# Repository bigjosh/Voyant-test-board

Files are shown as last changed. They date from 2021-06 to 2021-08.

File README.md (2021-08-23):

# Voyant Test Board

## Overview 

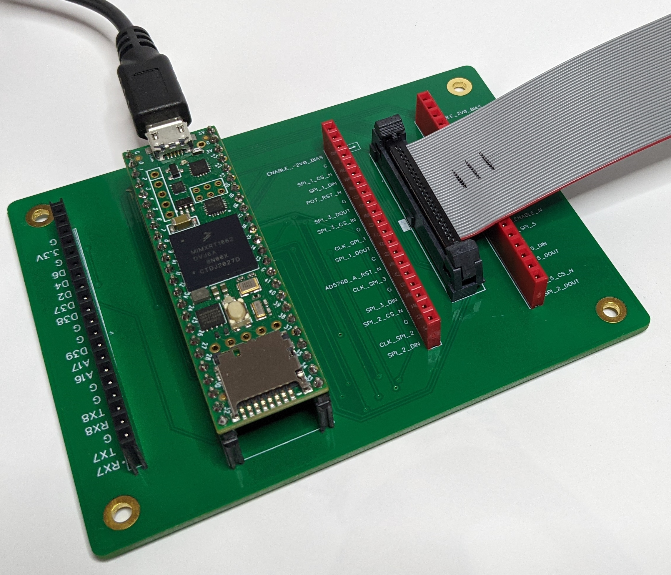
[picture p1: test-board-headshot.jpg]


A thin board+firmware that provides...

1. a text-based USB host serial command interface
2. an M50 connector with SPI and digital IO targets on the midboard via the M50 connector
2. a pass-thru serial port labeled "TEC_UART" via the M50 connector
3. an auxiliary header with additional pins available for digital IO, SPI, analog IO, and serial. 

Not that all pins from the M50 connector are also directly available via break-out headers for debugging. 

## Usage

### M50 labels

Note that all of the labels on the M50 pins are from the other side's point of view. For example, `TEC_RX` is going out of the test board into the `TEC`, and `TEC_TX` is going out of the `TEC`. `SPI_1_DIN` is going out of the test-board and into the `DIN` pin of the AD7490 on the mid-board  and `SPI_5_DOUT` goes out of the `SDO` (Slave Data Out) pin of the AD5142 and into the `MISO` (Master In, Slave Out) of the test-board.   

### Serial ports

When you connect the test board to a host computer via USB, you should see two virtual serial ports appear. One of these is the `command` and one is the `TEC_UART`, which is a pass-thru port. 

The command port is usually the first one, but not always. The most reliable way to tell is to load the Arduino IDE and 
look under "Tools->Port" and the command port will show up labeled as `Teensy`. The other new port will be the `TEC_UART` pass-thru.

#### `TEC_UART` pass-thru serial port

This is a direct pass-thru from the virtual USB port on the host to the `TEC_UART` RX and TX pins on the M50 connector. The baud rate on the serial port on the connector will track whatever the baud rate host serial port was set to when last connected to.

Note that the parity and bits are always N,8,1 but this can be changed in the firmware if needed.

#### Additional pass-thru serial ports

You can add additional serial pass-thru ports to the `uart_bridges` array in the firmware. You will likely want to connect them to either `Serial7` or `Serial8`, which are both available on the aux connector. 

To enable the corresponding USB virtual serial port, change the `USB Type` in `Tools->Board` in the Arduino IDE to `Tripple Serial` before downloading the new code. 

#### `command` serial port   

This serial connection accepts commands from the host according to the [API below](#api). These commands can send and receive data on the SPI ports, set the state of digital IO lines on the connector, and add delays.

Note that this virtual port will always run at USB maximum speed regardless of what baud rate it is set to on the host. That rate could be as high as 480Mbs, limited mostly by the host's USB bandwidth.

### SPI targets

There are a total of 6 SPI targets and each has an identifying one character tag name that is used to address the target in the API. Each SPI target has 4 associated pins: MISO, MOSI, CLK, and CS. The test-board is always the master and MISO is the only pin on each SPI port that is an input to the test-board. Any optional RESET pins are controlled using the [digital IO set command](#Digital-IO-Set-Request) below.   

Again, remember that the labels on the M50 connector are from the mid-board's point of view! A `DOUT` label on the test board means that pin is an output from the mid-board and an input to the test-board!

SPI targets `1`-`5` are labeled on the M50 connector. 

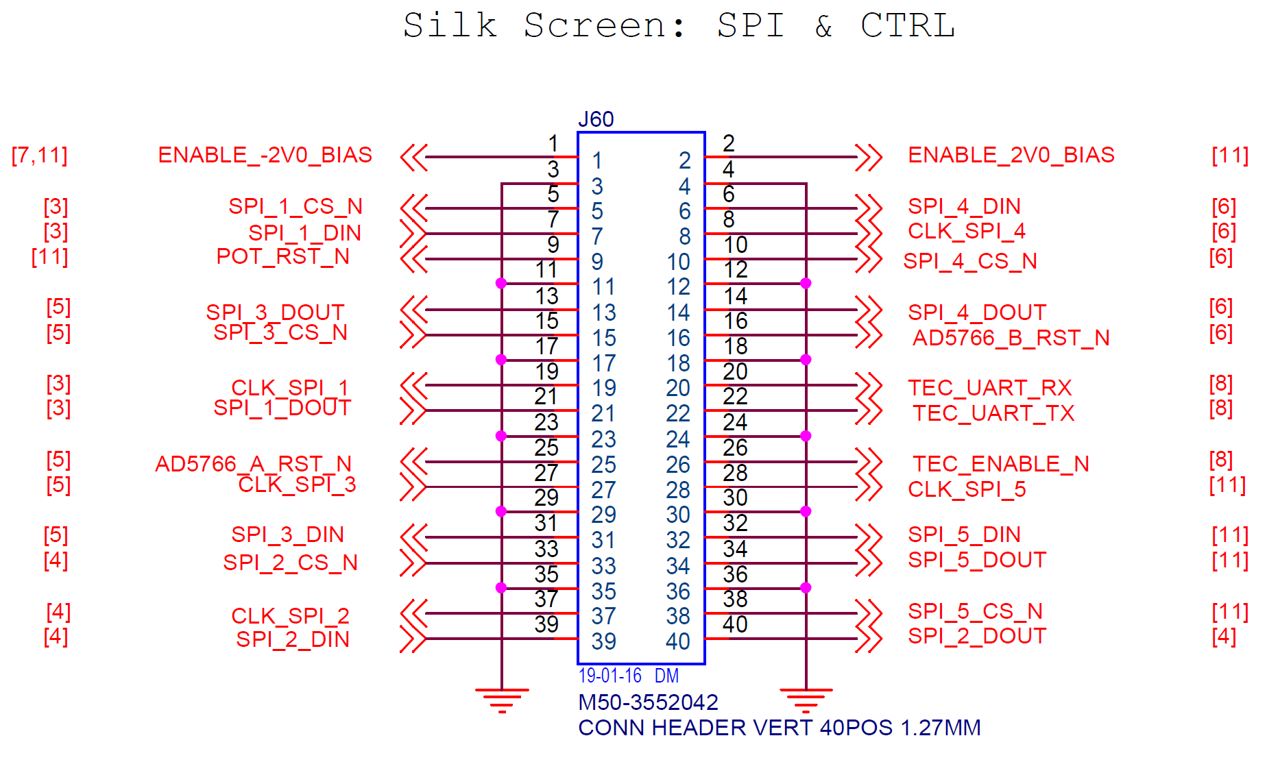
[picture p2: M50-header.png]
  

SPI target `A` is on the aux header with these pins (`MISO` is the only pin input to the test-board)...

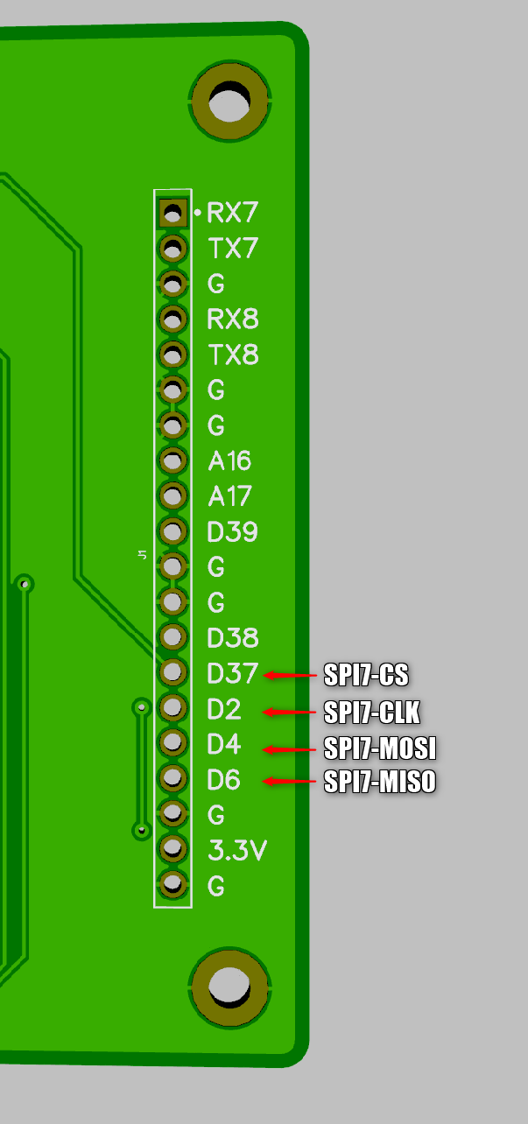
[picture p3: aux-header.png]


Note that currently all SPI ports run at 1MHz to reduce the chances of signal quality problems, but this can be increased on any or all ports with changes to the firmware. 

### Digital out targets

These are general purpose digital pins that can output either 0 volts or 3.3 volts. They are each capable of sinking or sourcing up to 10mA. Digital outputs are all initialized to `0` on power up. 

They are listed in the [IO target tags table](#IO-target-tags) and are controlled using the [digital IO set command](#Digital-IO-Set-Request) below. 

## API

The API is a set of ASCII text commands and responses that are sent over the command serial port. Each command and response is a line of ASCII text. Requests can be terminated with any combination of carriage returns and/or line feeds. Responses are always terminated with a carriage return character (ASCII 13, or '\r') and a newline character (ASCII 10, or '\n').

Every command sent to the test board generates a single response back to the host. All commands are currently synchronous so the responses will always be sent in the same order as the their requests.   

The maximum line length in either direction is currently 255 bytes.

### Cheat Sheet

If necessary, download the firmware to the board per these [instructions](#Development-environment).

Connect to first USB serial port that shows up on your host. All requests and responses are single line of ASCII text.

`T1771FF5600` where "T"=Transfer rerquest, "1"= the tag for SPI1 target, sends the three bytes 77h, 1fh, f5h. Returns with...

`S567483` where "S"=Transfer response and 56h, 74h, and 83h are the bytes read from the SPI. 

`;This is a comment becuase it starts with semicolon. Send or ignore me.` 

`IN1` where "I" = Set digital IO pin request, "N"= the tag for `ENABLE_-2V0_BIAS` pin, "1" = Set pin HIGH. Returns with...

`H` where "H" = Set completed.  

`D1000` where "D" = Delay command and "1000" = 1000 milliseconds. Returns (after the delay) with...

`C` where "C" = Delay completed. 

Getting back an `E` indicates an error. A comment that tells you why.

All commands are synchronous (for now).

All SPI and digital IO signals are 3.3 volts.

All SPIs run at 1Mhz (for now). 

### Target Tags

These 1 char tags are sent with each SPI and IO command to specify which target. The actual tag char is arbitrary, but I tried to pick ones that make sense and are easy to remember.    

#### SPI target tags

```
  // Taken directly from schamtics. The numbers here refer to the pin numbers on the Teensy. 
  // The tags are taken from the SPI labels on the M50 connector diagram except for `A` which is on the AUX header.
  
  // spi_target( uint8_t mosi, uint8_t miso, uint8_t clk , uint8_t cs , uint32_t bps ) 
  
  {'1', Spi_target( 33 , 32 , 31 , 30 , SPI_BPS ) }, 
  {'2', Spi_target( 22 , 21 , 20 , 19 , SPI_BPS ) }, 
  {'3', Spi_target( 26 , 12 , 13 ,  0 , SPI_BPS ) }, 
  {'4', Spi_target( 11 , 12 , 13 , 10 , SPI_BPS ) }, 
  {'5', Spi_target( 17 , 16 , 15 , 14 , SPI_BPS ) }, 
  
  {'A', Spi_target(  4 ,  6 ,  2 , 37 , SPI_BPS ) },        // On the aux header on the right side of the PCB
```

#### IO target tags

```
  // key in the map is the `target` char that the API uses to specify which IO target. 
  // The tags are arbitrary (but meant to hopefully be mnemonic)   
  // The pin refers to the Teensy pin number. 
  // io_target( uint8_t pin ) 

  // The comment is the label on the pin on the M50 connector
  
  {'N', Io_target( 24 ) },    // ENABLE_-2V0_BIAS
  {'P', Io_target( 25 ) },    // ENABLE_2V0_BIAS
  
  {'3', Io_target(  3 ) },    // AD5766_A_RST_N (SPI3)
  {'4', Io_target(  9 ) },    // AD5766_B_RST_N (SPI4)
  {'5', Io_target( 18 ) },    // POT_RST_N      (SPI5)

  {'T', Io_target(  5 ) },    // TEC_ENABLE_N   (TEC_UART)

  // The comment is the label on the Aux header  

  {'9', Io_target( 39 ) },    // D39
  {'8', Io_target( 38 ) },    // D38
```

### Protocol

#### Omnibus Error Response

The error response is sent in response to any invalid or malformed line. 

If `DEBUG` is `#defined` as `1`, then each error response will be preceded by a comment with text describing the error condition.

All errors should be considered exceptions and indicate either a logic problem or a config mismatch. 

##### Format 

| Content | Bytes | Desc |
| - | - | - |
| `E` | 1 | Specifies Error Response |

##### Example
```
;Invlaid hex digit in SPI transfer
E
```

#### SPI Transfer Request

Sends a series of bytes to an SPI target and simultaneously reads the same number of bytes from that target.

##### Request Format:

| Content | Bytes | Desc |
| - | - | - |
| `T` | 1 | Specifies transfer request |
| tag | 1 | Specifies SPI target port. From [SPI target tags list](#SPI-target-tags) above. |  
| data | 2,4,6,... | Variable length of bytes to send, each as a two digit ASCII hex number |

##### Example
```
TA0C0A0F0E90
```

Sends the bytes 0x0c, 0x0a, 0x0f, 0x0e , 0x90 to SPI port target `A` (which is on the AUX header).   

##### Transfer Response

| Content | Bytes | Desc |
| - | - | - |
| `S` | 1 | Specifies transfer success response |  
| data | 2,4,6,... | Variable length of bytes received, each as a two digit ASCII hex number. |

The number of bytes received will always be equal to the number sent in the corresponding transfer request command. 

For now, all SPI transfers are synchronous so the response will immediately follow the request.  

#### Digital IO Set Request

Sets the output voltage on one of the IO pins. 

##### Request Format:

| Content | Bytes | Desc |
| - | - | - |
| `I` | 1 | Specifies IO Set command |
| tag | 1 | Specifies target IO port. From [IO target tags list](#IO-target-tags) above. |  
| `0` or `1`  | 1 |  `0`= sets pin to 0 volts, `1`=sets pin to 3.3 volts.  |

##### IO Response

| Content | Bytes | Desc |
| - | - | - |
| `H` | 1 | Specifies IO set success response |  

#### Delay Request

Adds a delay while processing requests. 

##### Request Format:

| Content | Bytes | Desc |
| - | - | - |
| `D` | 1 | Specifies IO Set command |
| millis | variable | Specifies number of milliseconds to pause. |  

Note that millis will overflow if number specified in command is larger than 32 bits. 

## Development environment

To edit the firmware, you need to follow these steps to install the development environment...
 
``` 
 1. Install Arduino IDE https://www.arduino.cc/en/software
 2. Install Teensiduino from https://www.pjrc.com/teensy/td_download.html 
 3. Set the following in the Arduino Tools menu...
 
    Board     = Teensy->Teensyduino->Teensy 4.1
    USB Type  = Dual Serial
    CPU Speed = 600Mhz (default)
    Port      = (find the Teensy 4.1 board on this list)
 ```

Then open the `firmware.ino` file in the `software` section of this repo using the Arduino IDE, make any desired changes, and then click on the right-pointing arrow in the upper left corner of the IDE window. This will upload the new code to the Teensy board and run it. 

### Examples

Copy and paste these into a `putty` window connected to the command port. 

#### SPI1 (AD7490)

```
;First send two transactions with DIN high to reset all the state bits
T1FFFF
T1FFFF
;Read a sample from address 0 ( 0b10aa aa11 0101 with aaaa=0000. Note the trailing 0 is ignored, just there to clock out final 4 bits )
; Send twice for this demo since the response for a command is clocked out on the NEXT request
T18350
T18350
; The above command should generate a response `S10xxx` where `0` is the address we requested above and xxx is the reading
;Read a sample from address 1 ( 0b10aa aa11 0101 with aaaa=0001. Note the trailing 0 is ignored, just there to clock out final 4 bits )
; Send twice for this demo since the response for a command is clocked out on the NEXT request
T18750
T18750
; The above command should generate a response `S11xxx` where `1` is the address we requested above and xxx is the reading
;Read a sample from address 15 ( 0b10aa aa11 0101 with aaaa=1111. Note the trailing 0 is ignored, just there to clock out final 4 bits )
; Send twice for this demo since the response for a command is clocked out on the NEXT request
T1BF50
T1BF50
;The above command should generate a response `S1fxxx` where `1` is the address we requested above and xxx is the reading
; With an AREF of 2.5V and an AA battery attached to input #15, I get a response of  Sf42a 
```

#### SPI2 (AD7124)

```
;Reset command
T2FFFFFFFFFFFFFFFF
;Read command (high bits 0b01xxxxxx) on `CHANNEL_0` register ((0x09 or 0bxx001001). Trailing `0000` clocks out the result.   
T2490000
;The above command should generate a response `S008001` where `00` is always the first byte on this chip,
; and the `8001` is the reset value of the register.   
```

#### SPI3 & SPI4 (AD5766)

Note these commands address `AD5766-A` on SPI3, but will work on `AD5766-B` on SPI4 if you change all the targets to `4`.

```
;~Reset=LOW (resets chip)
I30
; T10=100ns, so 1ms more than enough
D1
;~Reset=HIGH
I31
; "Minimum time between a reset and the subsequent successful write is typically 25 ns."
D1
; "Always issue a software reset before writing to the span register."
; Full Software reset = 0b0111 0000 0001 0010 0011 0100
T3701234
; "outputs are clamped to ground...until a valid write sequence is made to the span register"
; Set span Full Scale , -10V to 10V = 0b0100 0000 0000 0000 0001 0110
T3400017
;Trigger scope
D1
; Make an interesting ramp on OUT0....
; Write 16 bit value to to DAC register 0 = 0010 0000 vvvv vvvv vvvv vvvv
T3201111
D1
T3202222
D2
T3203333
D3
T3205555
D5
;Half way
T3208000
D5
T320AAAA
D9
T320FFFF
D14
;Bring it back home
T3200000
;Go check your osciliscope

```

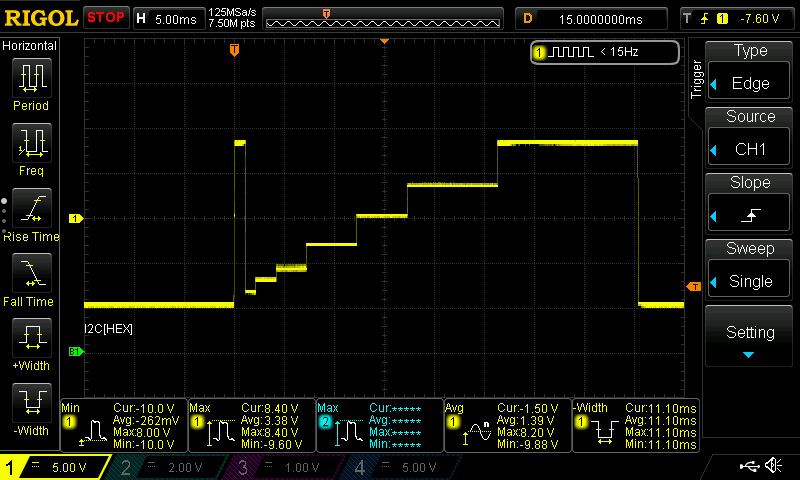
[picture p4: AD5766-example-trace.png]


#### D39 digital output

This example generates a 1 second wide, 3.3 volt high square pulse on pin D39 of the AUX connector here...



```
; Assumes D39 is at 0 volts (power up state)
;Set voltage on D39 to 3.3 volts 
I91
;Delay 1 second
D1000
;Set voltage on D39 back to 0 volts 
I90
```



## Future directions

### Faster SPI

This board can easily support *much* faster SPI speeds. To change the speeds, edit the last param `spi_targets` structure init. Do note that this board can easily go so fast that my logic analyzer can not keep up (the whole transaction looks like a glitch), so work your way up slowly.

### Async SPI

It is possible to start a new SPI transaction while others are still running. To support this, we would need to add a tag to the SPI response so you could see which transfer completed. 

### IO inputs 

We could also read the digital IO pins with a new command.

### Analog inputs

Same as above. Decent ADC, 2 pins are already exposed on the aux header.

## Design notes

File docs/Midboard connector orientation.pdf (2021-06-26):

# Mid board Connectors in Optics Head

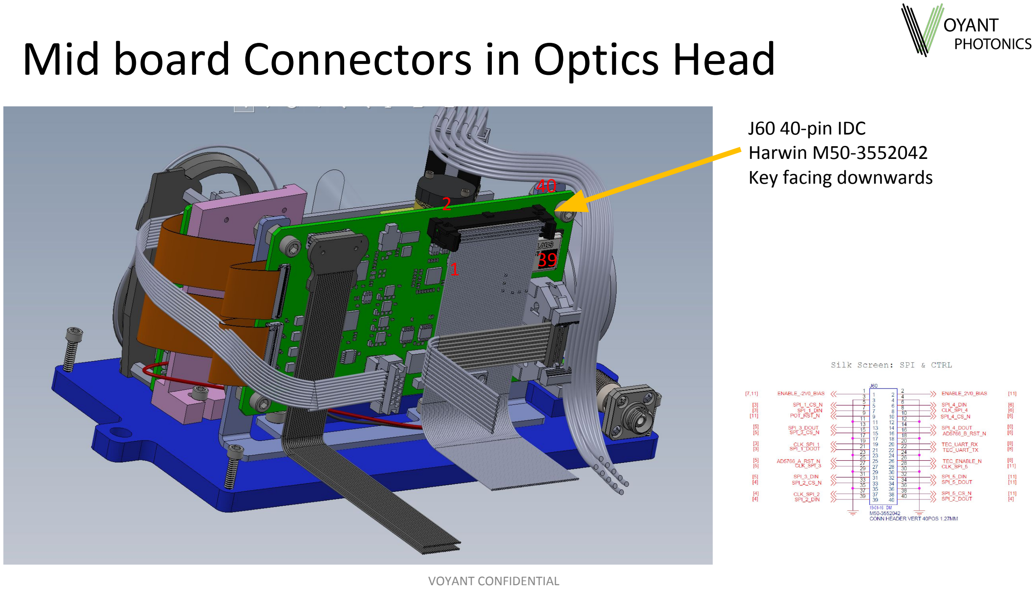
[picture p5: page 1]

VOYANT CONFIDENTIAL

J60 40-pin IDC
Harwin M50-3552042
Key facing downwards

1

39

2

40

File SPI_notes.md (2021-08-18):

## SPI1 - AD7490

CLK idle HIGH, sample on CS falling edge?

>The remaining
>address bits and data bits are then clocked out by subsequent
>SCLK falling edges, beginning with the second address bit,
>ADD2. Thus, the first SCLK falling edge on the serial clock has
>the ADD3 address bit provided and also clocks out address bit
>ADD2. The final bit in the data transfer is valid on the 16th
>falling edge, having being clocked out on the previous (15th)
>falling edge. 

https://www.analog.com/media/en/technical-documentation/data-sheets/AD7490.pdf



We always write 16 bits and at the same time read the 16 bit result of the previous conversion. 



WRITE must be 1. PMx should both be 1 (power on). Shadow 0 for testing. WEAK is interesting. If 1 then the first bit of the address of previous convversion appears on DOUT when CS goes low - we want this so we always get the address back on evvery conversion. 

You initialize the interface by sending two transactions in a row of 0xFFFF each....


So for testing we will send 0b10aaaa110101. We will change aaaa and see if the aaaa changes in the next readout. 

## SPI2 - AD7124

Mode 3

https://www.analog.com/media/en/technical-documentation/data-sheets/AD7124-4.pdf
Page 38:


## SPI3 & SPI4 - AD5766

Looks like CLK idle HIGH, sampled on LOW - so Mode 2

24 bit(3 byte) commands. 

https://www.analog.com/media/en/technical-documentation/data-sheets/ad5766-5767.pdf





Maximum SCLK frequency is 50 MHz for write mode and 10 MHz for readback mode.
Minimum time between a reset and the subsequent successful write is typically 25 ns.

100ns typ RESET2 pulse width low
100ns typ RESET2 pulse activation time

## SPI 5 - AD5142

Looks like CLK idle HIGH, sampled on LOW - so Mode 2

Chip is WRITE only. DOUT is only for daisy chain. 

https://www.analog.com/media/en/technical-documentation/data-sheets/AD5122_5142.pdf

"Data is loaded in at the SCLK falling edge transition, as
shown in Figure 3 and Figure 4. "



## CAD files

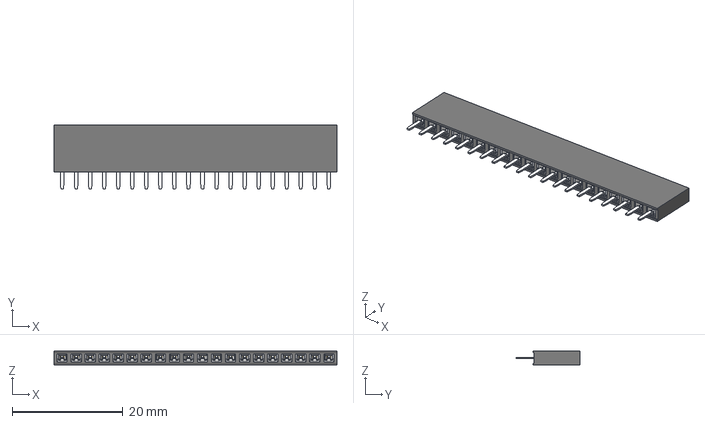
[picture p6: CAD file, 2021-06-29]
hardware/diptrace/3d models/m20-7822042_asm.stp
51.2 x 11.5 x 2.50 mm
M20-78220_MOULD
M20-782_CONTACT x 20

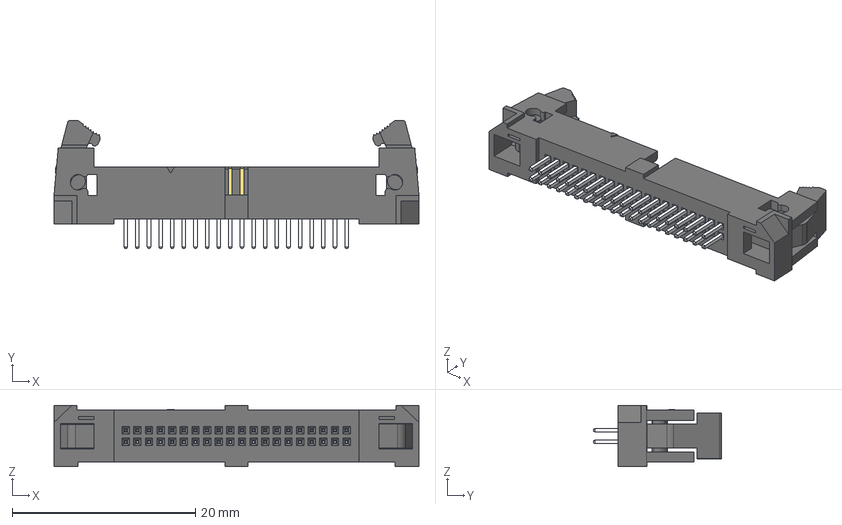
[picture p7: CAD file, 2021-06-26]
hardware/diptrace/3d models/m50-3552042_asm.stp
39.9 x 14.0 x 6.67 mm
M50-35520_MOULD
M50-355_PIN x 40
M50-355_LATCH x 2

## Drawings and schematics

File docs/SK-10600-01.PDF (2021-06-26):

TABLE OF CONTENTS | REVISION HISTORY
PAGE | REVISION

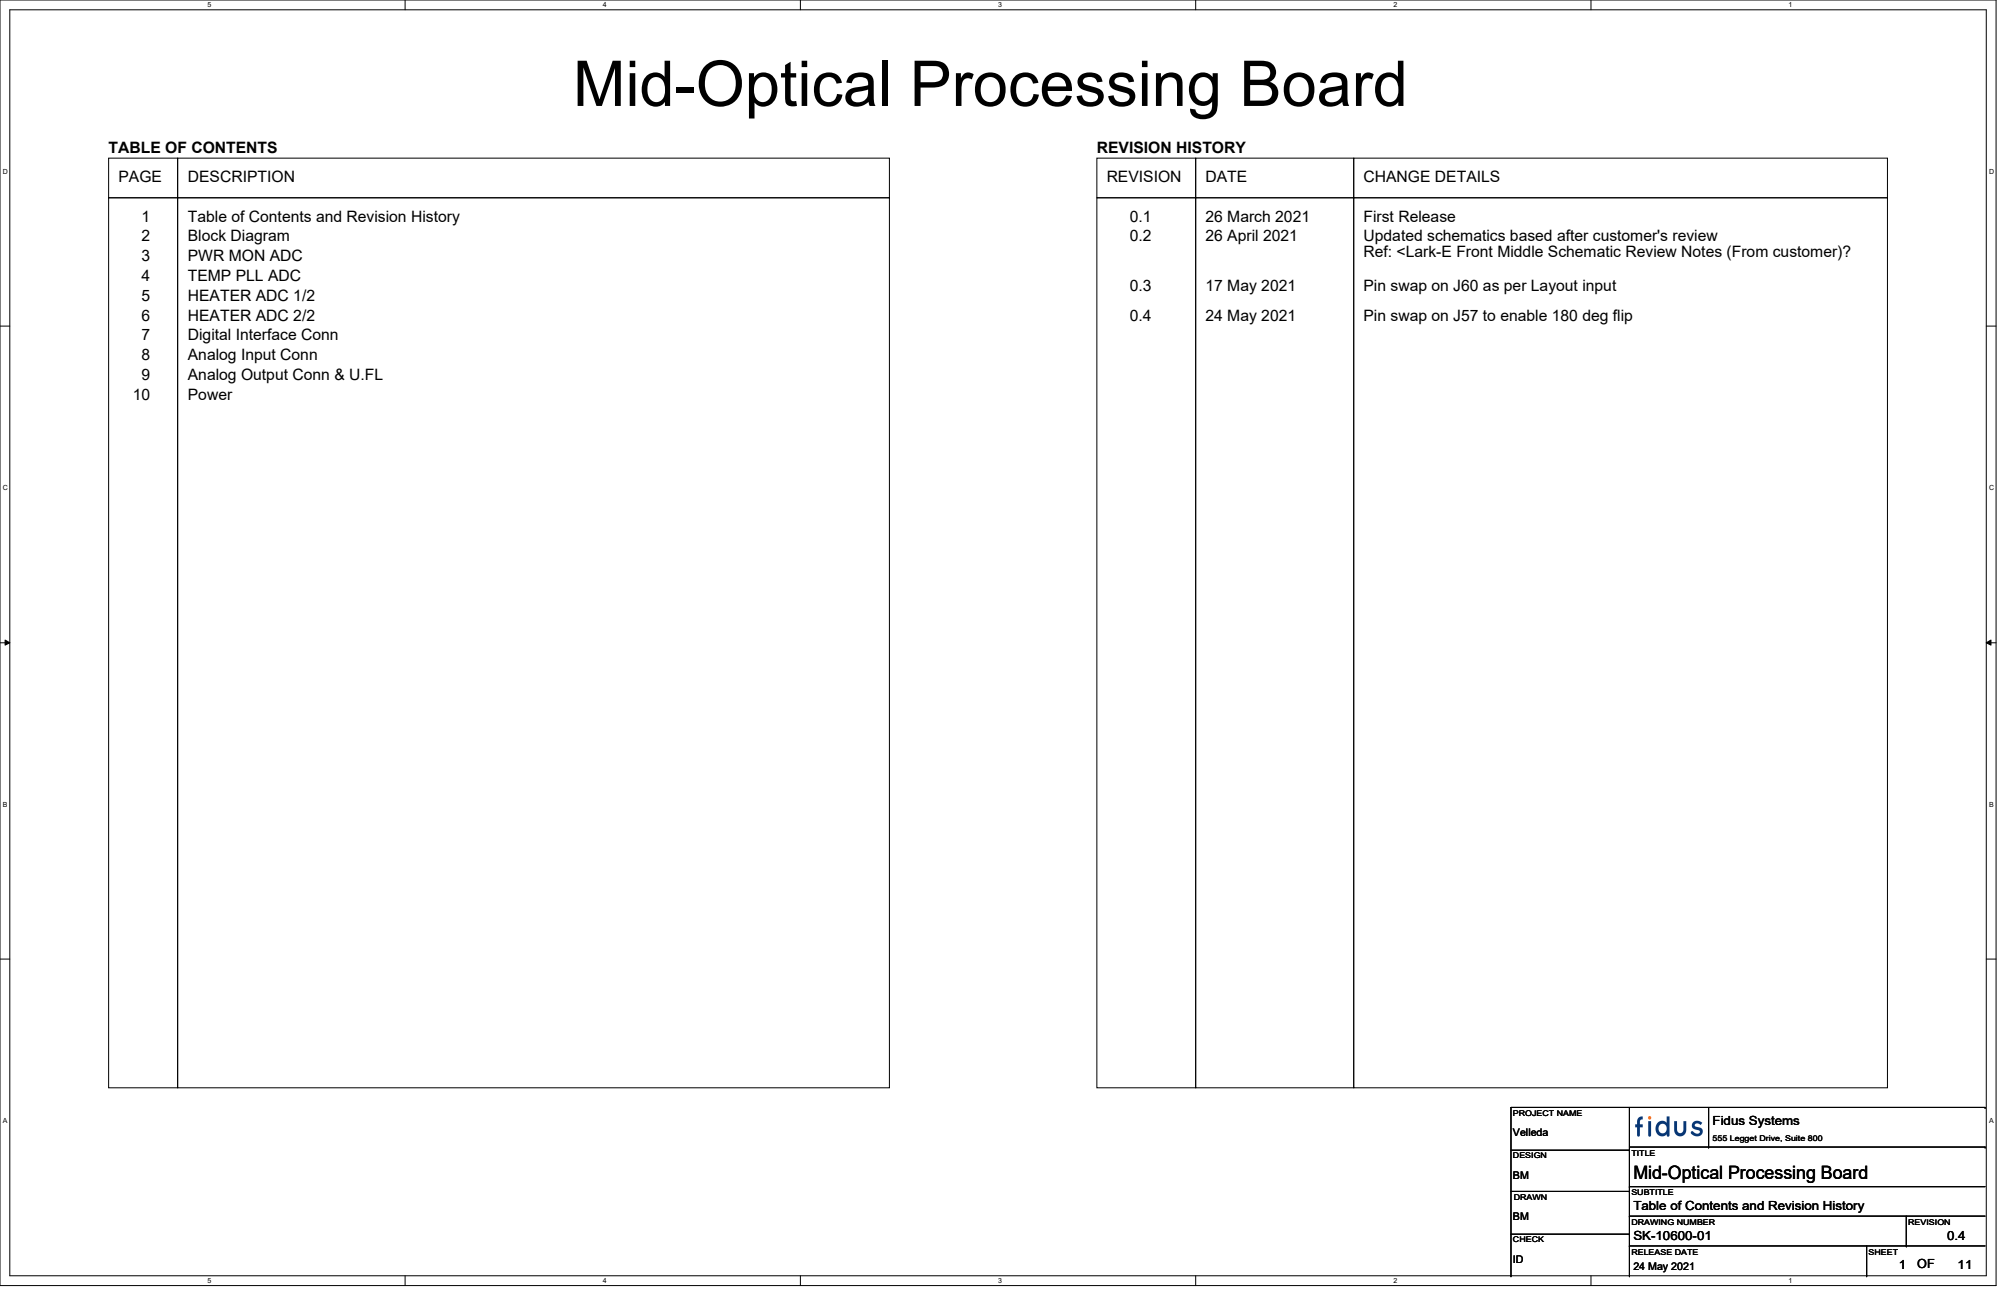
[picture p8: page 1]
DESCRIPTION; DATE; CHANGE DETAILS; First Release; 26 March 2021 26 April 2021; 17 May 2021; Pin swap on J60 as per Layout input; 24 May 2021; Pin swap on J57 to enable 180 deg flip; DRAWN; CHECK

Mid-Optical Processing Board

Table of Contents and Revision History
Block Diagram
PWR MON ADC
TEMP PLL ADC
HEATER ADC 1/2
HEATER ADC 2/2
Digital Interface Conn
Analog Input Conn
Analog Output Conn & U.FL
Power

0.2 Updated schematics based after customer's review

Ref: <Lark-E Front Middle Schematic Review Notes (From customer)?

PROJECT NAME PROJECT NAME PROJECT NAME | | Fidus Systems Fidus Systems Fidus Systems 555 Legget Drive, Suite 800 Velleda 555 Legget Drive, Suite 800 Velleda 555 Legget Drive, Suite 800 Velleda

DESIGN DESIGN DESIGN BM BM BM | TITLE TITLE TITLE Mid-Optical Processing Board Mid-Optical Processing Board Mid-Optical Processing Board

SUBTITLE

DRAWING NUMBER SK-10600-01 | REVISION 0.4

RELEASE DATE 24 May 2021 | SHEET 1 11 1 11 1 11 OF

# Current Schematic Block Diagram

## TO FPGA BACK BOARD

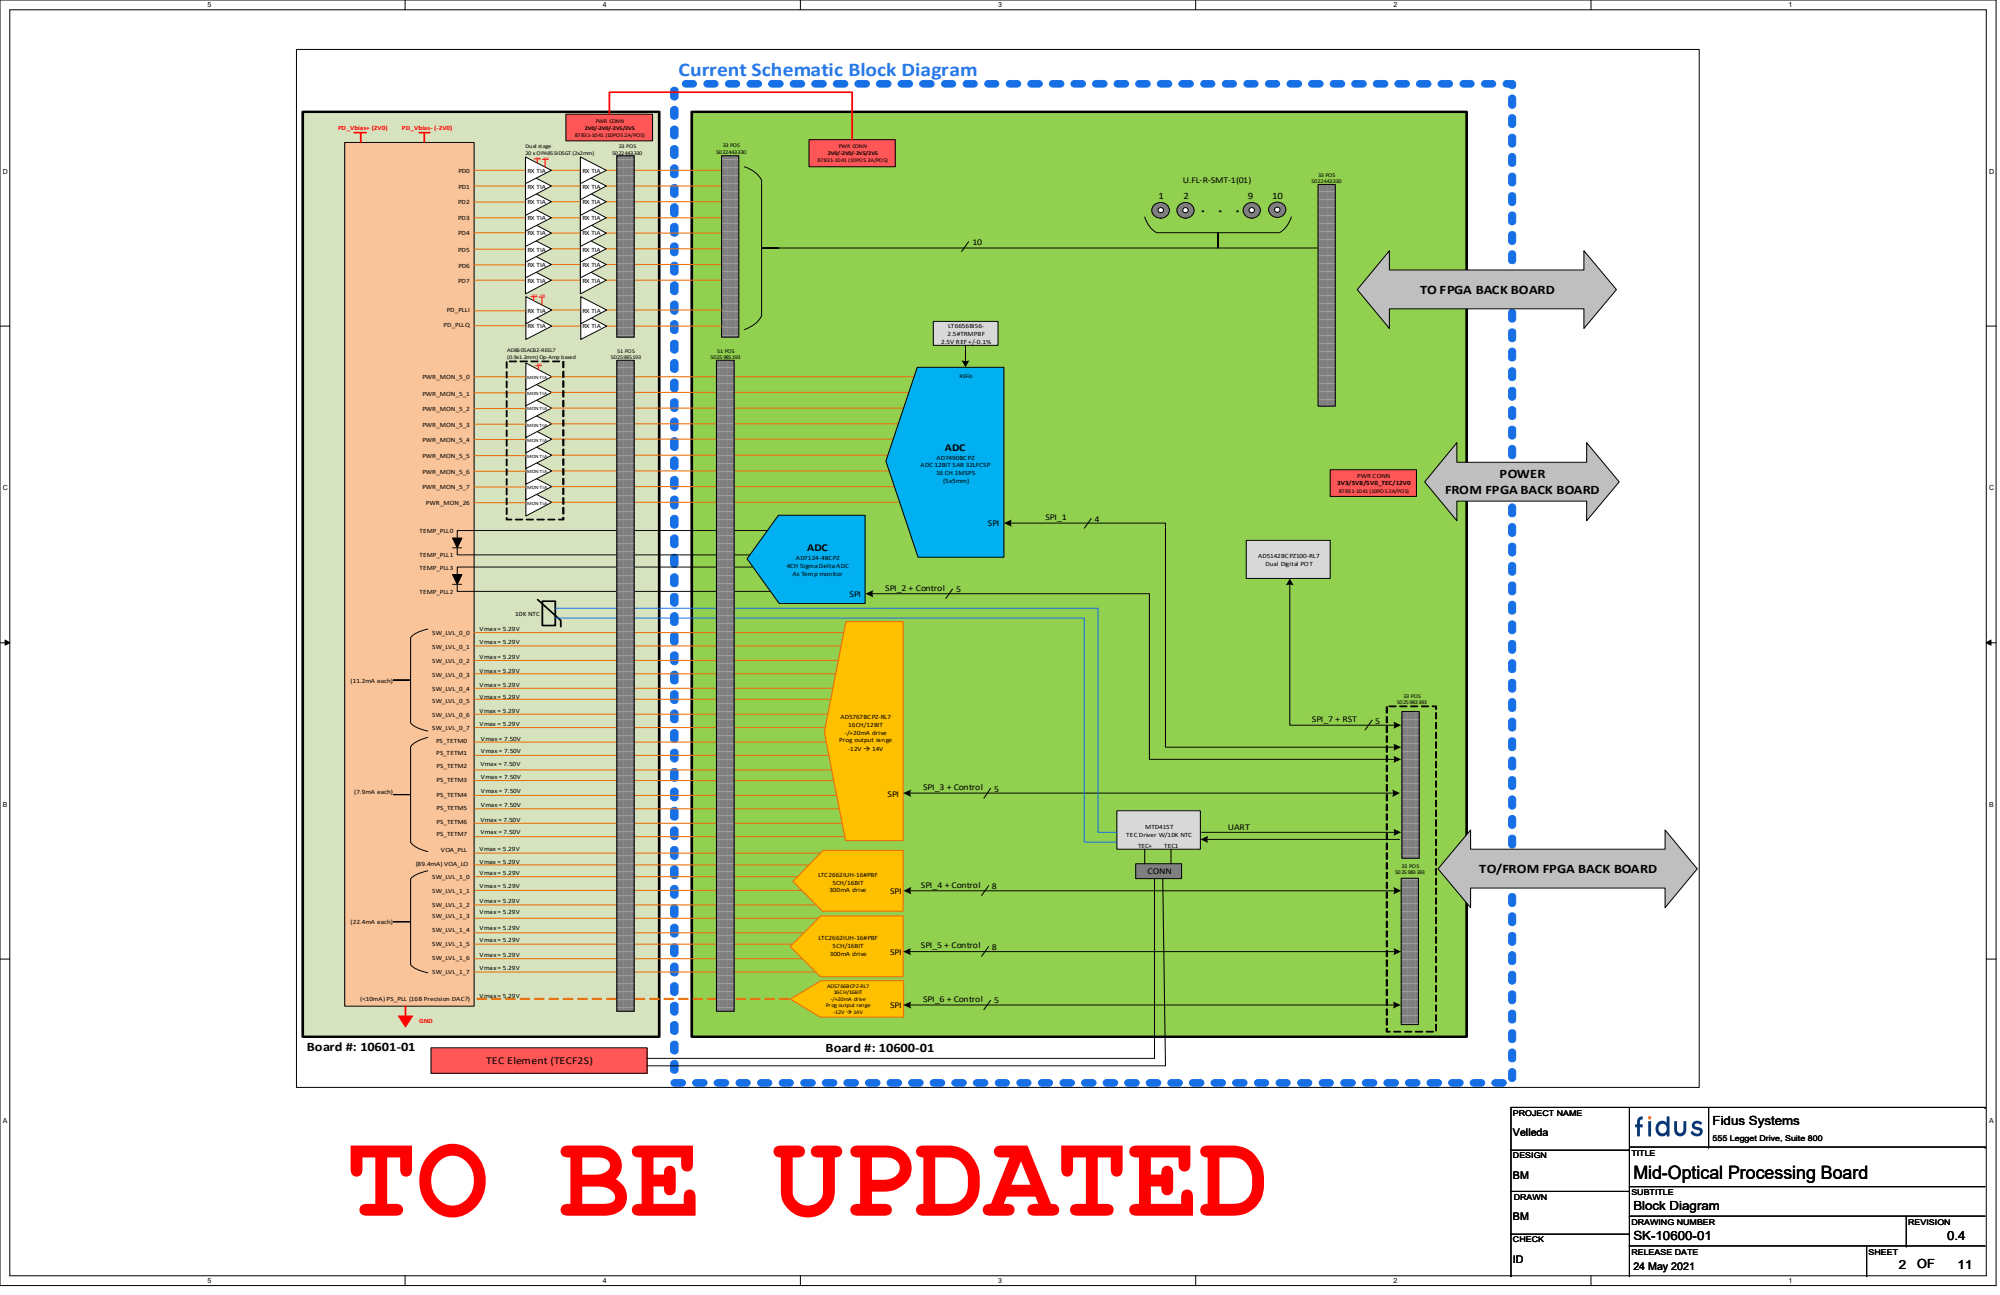
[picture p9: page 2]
MON TIA; PD_PLLI; PD_PLLQ; PWR_MON_5_0; PWR_MON_5_1; PWR_MON_5_2; PWR_MON_5_3; PWR_MON_5_4; PWR_MON_5_5; PWR_MON_5_6; PWR_MON_5_7; PWR_MON_26; (<10mA) PS_PLL (16B Precision DAC?); (89.4mA) VOA_LO; SW_LVL_0_0; SW_LVL_0_1; SW_LVL_0_2; SW_LVL_0_3; SW_LVL_0_4; SW_LVL_0_5; SW_LVL_0_6; SW_LVL_0_7; SW_LVL_1_0; SW_LVL_1_1; SW_LVL_1_2; SW_LVL_1_3; SW_LVL_1_4; SW_LVL_1_5; SW_LVL_1_6; SW_LVL_1_7; PS_TETM0; PS_TETM1; PS_TETM2; PS_TETM3; PS_TETM4; PS_TETM5; PS_TETM6; PS_TETM7; VOA_PLL; (11.2mA each)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

AD86 05ACBZ-REEL7
(0.9x1.3mm) Op-Amp based

FROM FPGA BACK BOARD

AD7124-4BCPZ
4CH Sigma Delta ADC
As Temp monitor

Dual Digital POT

TEC Driver W/10K NTC

TO/FROM FPGA BACK BOARD

Vmax = 5.29V
TO BE UPDATED

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

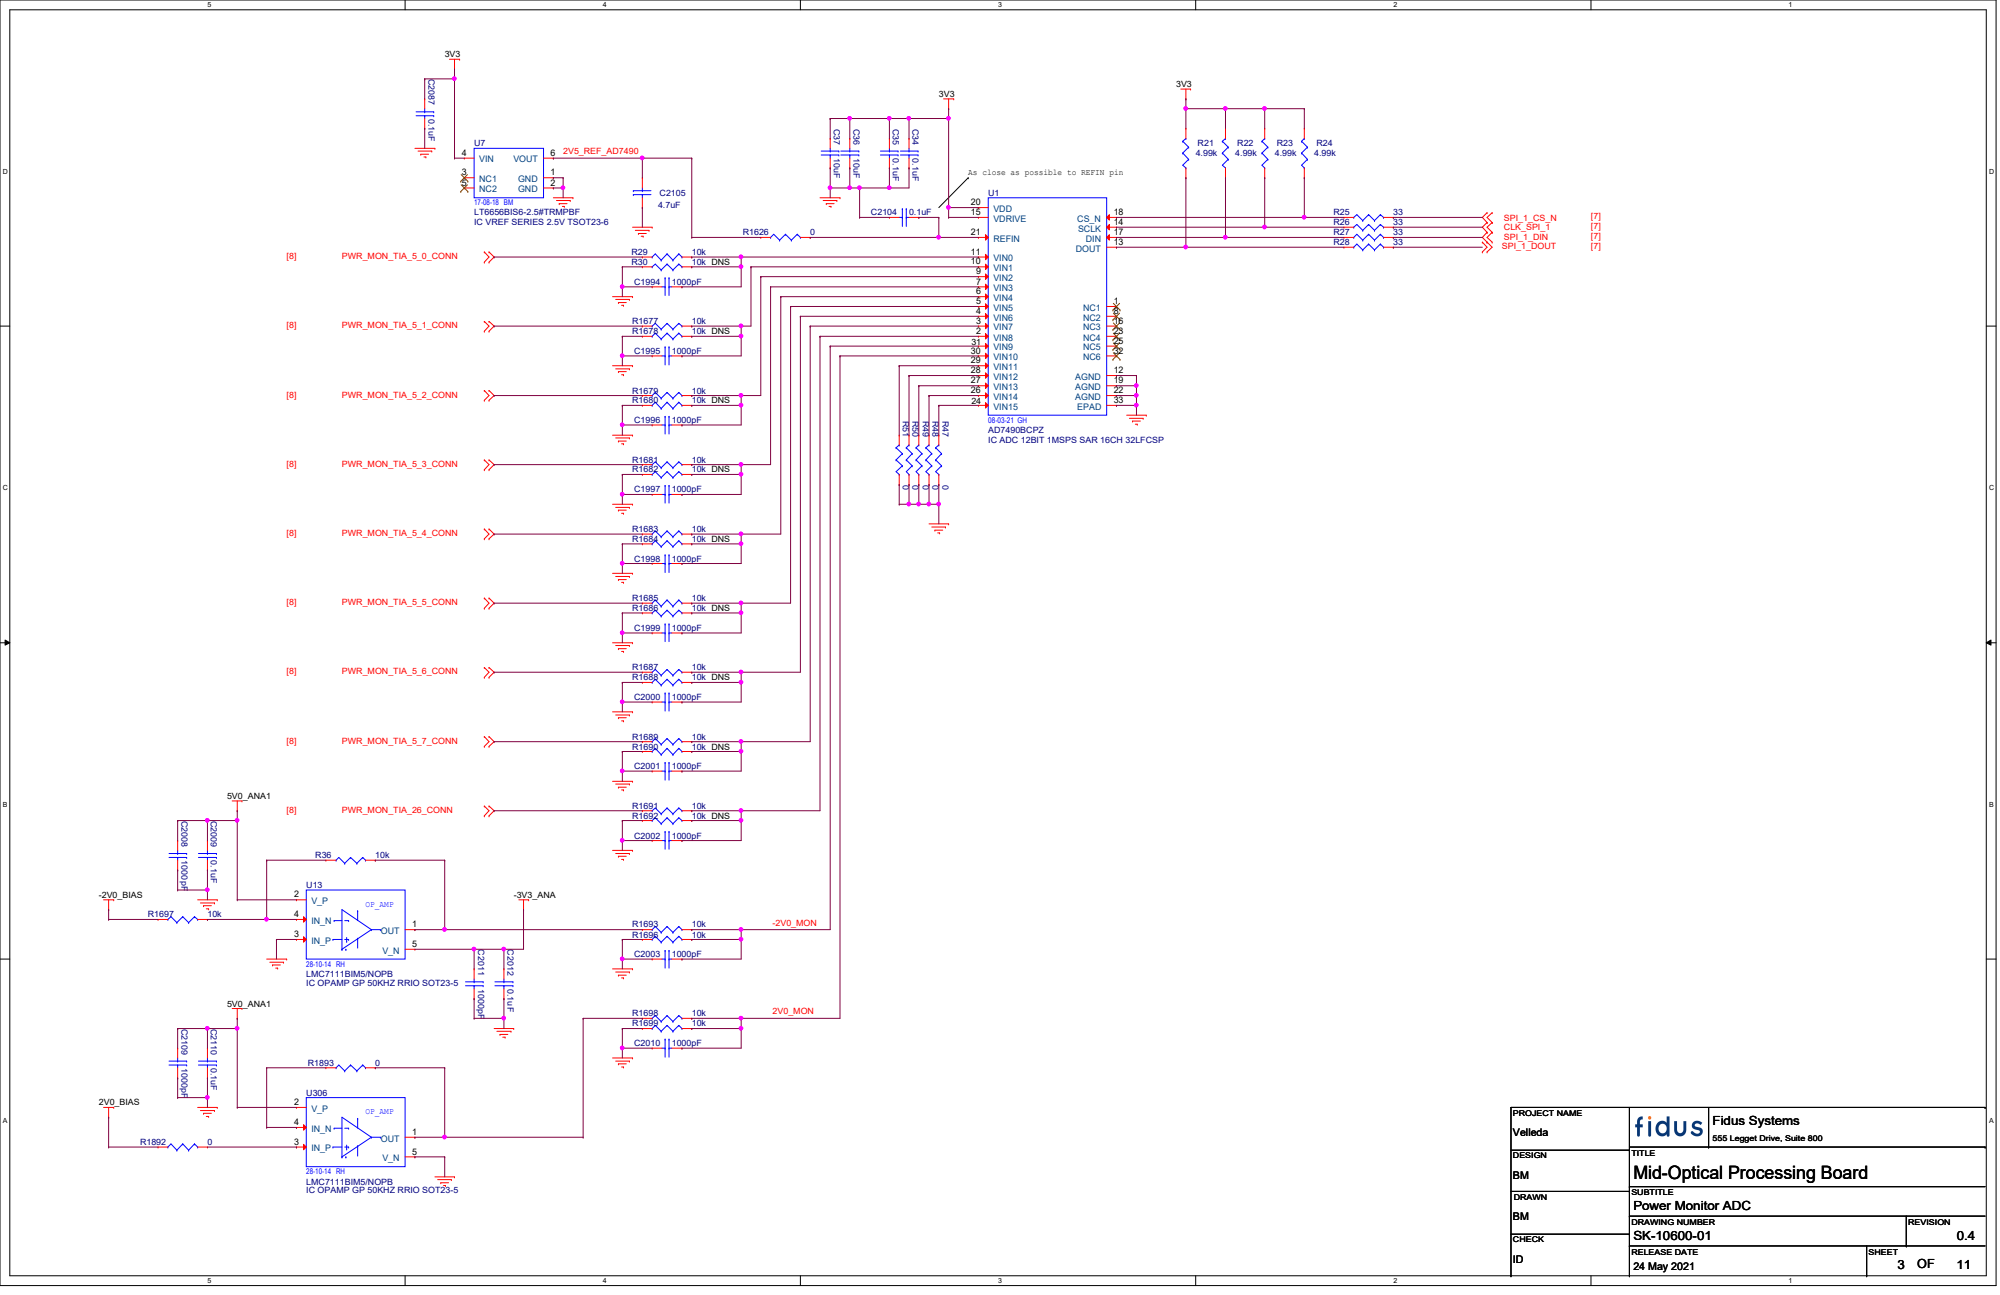
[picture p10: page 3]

As close as possible to REFIN pin

LMC7111BIM5/NOPB
IC OPAMP GP 50KHZ RRIO SOT23-5

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

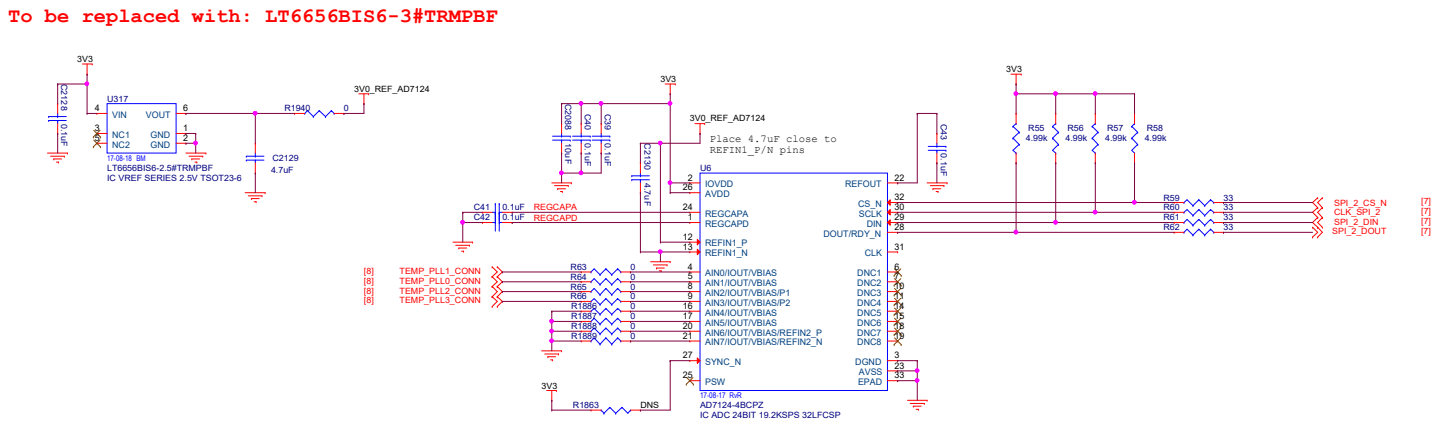
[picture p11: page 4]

To be replaced with: LT6656BIS6-3#TRMPBF

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

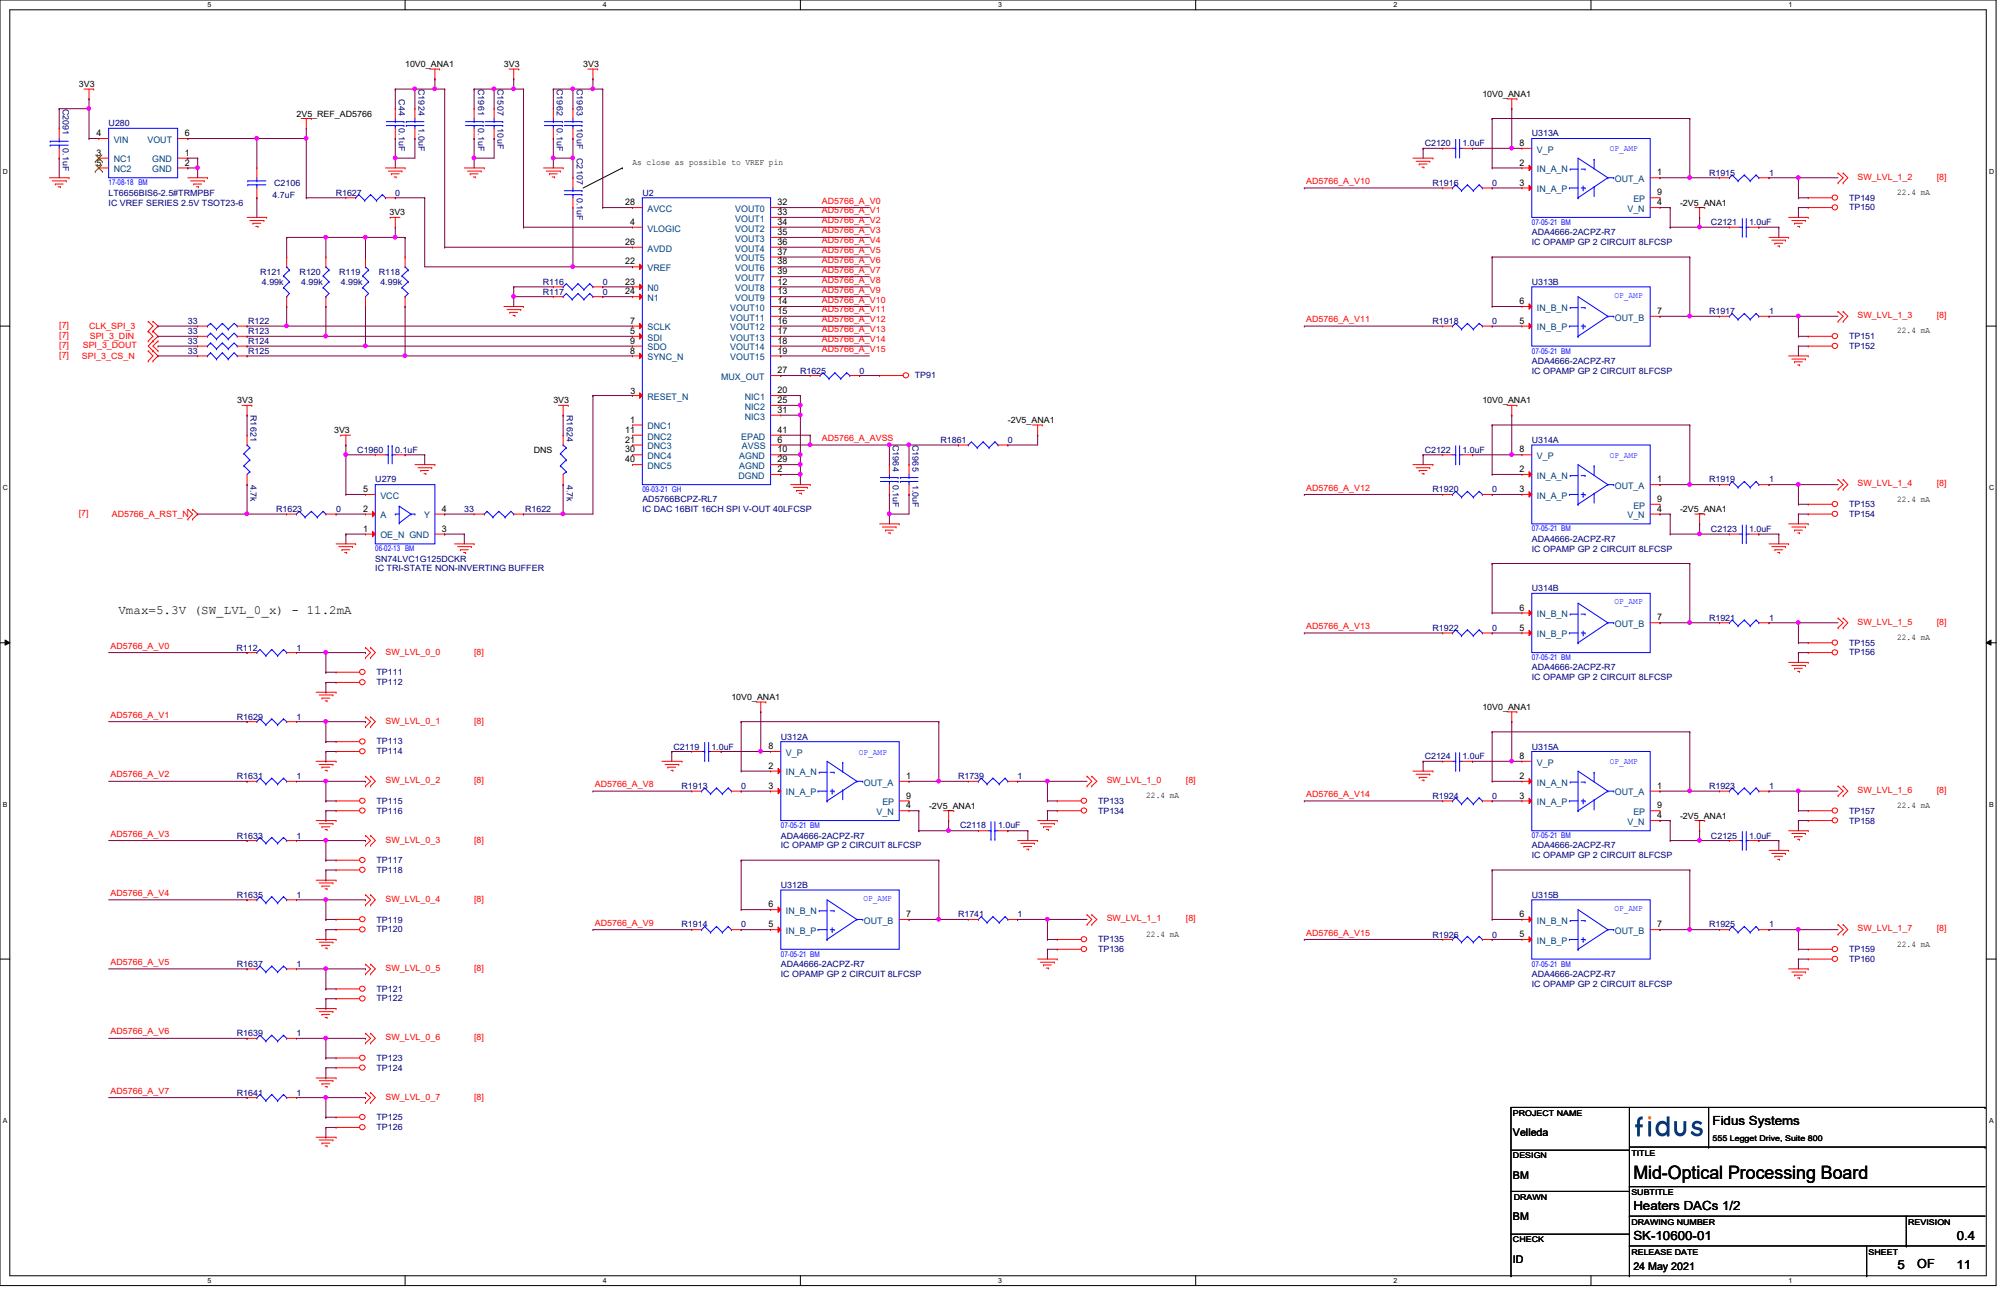
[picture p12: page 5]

As close as possible to VREF pin

SN74LVC1G125DCKR
IC TRI-STATE NON-INVERTING BUFFER

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

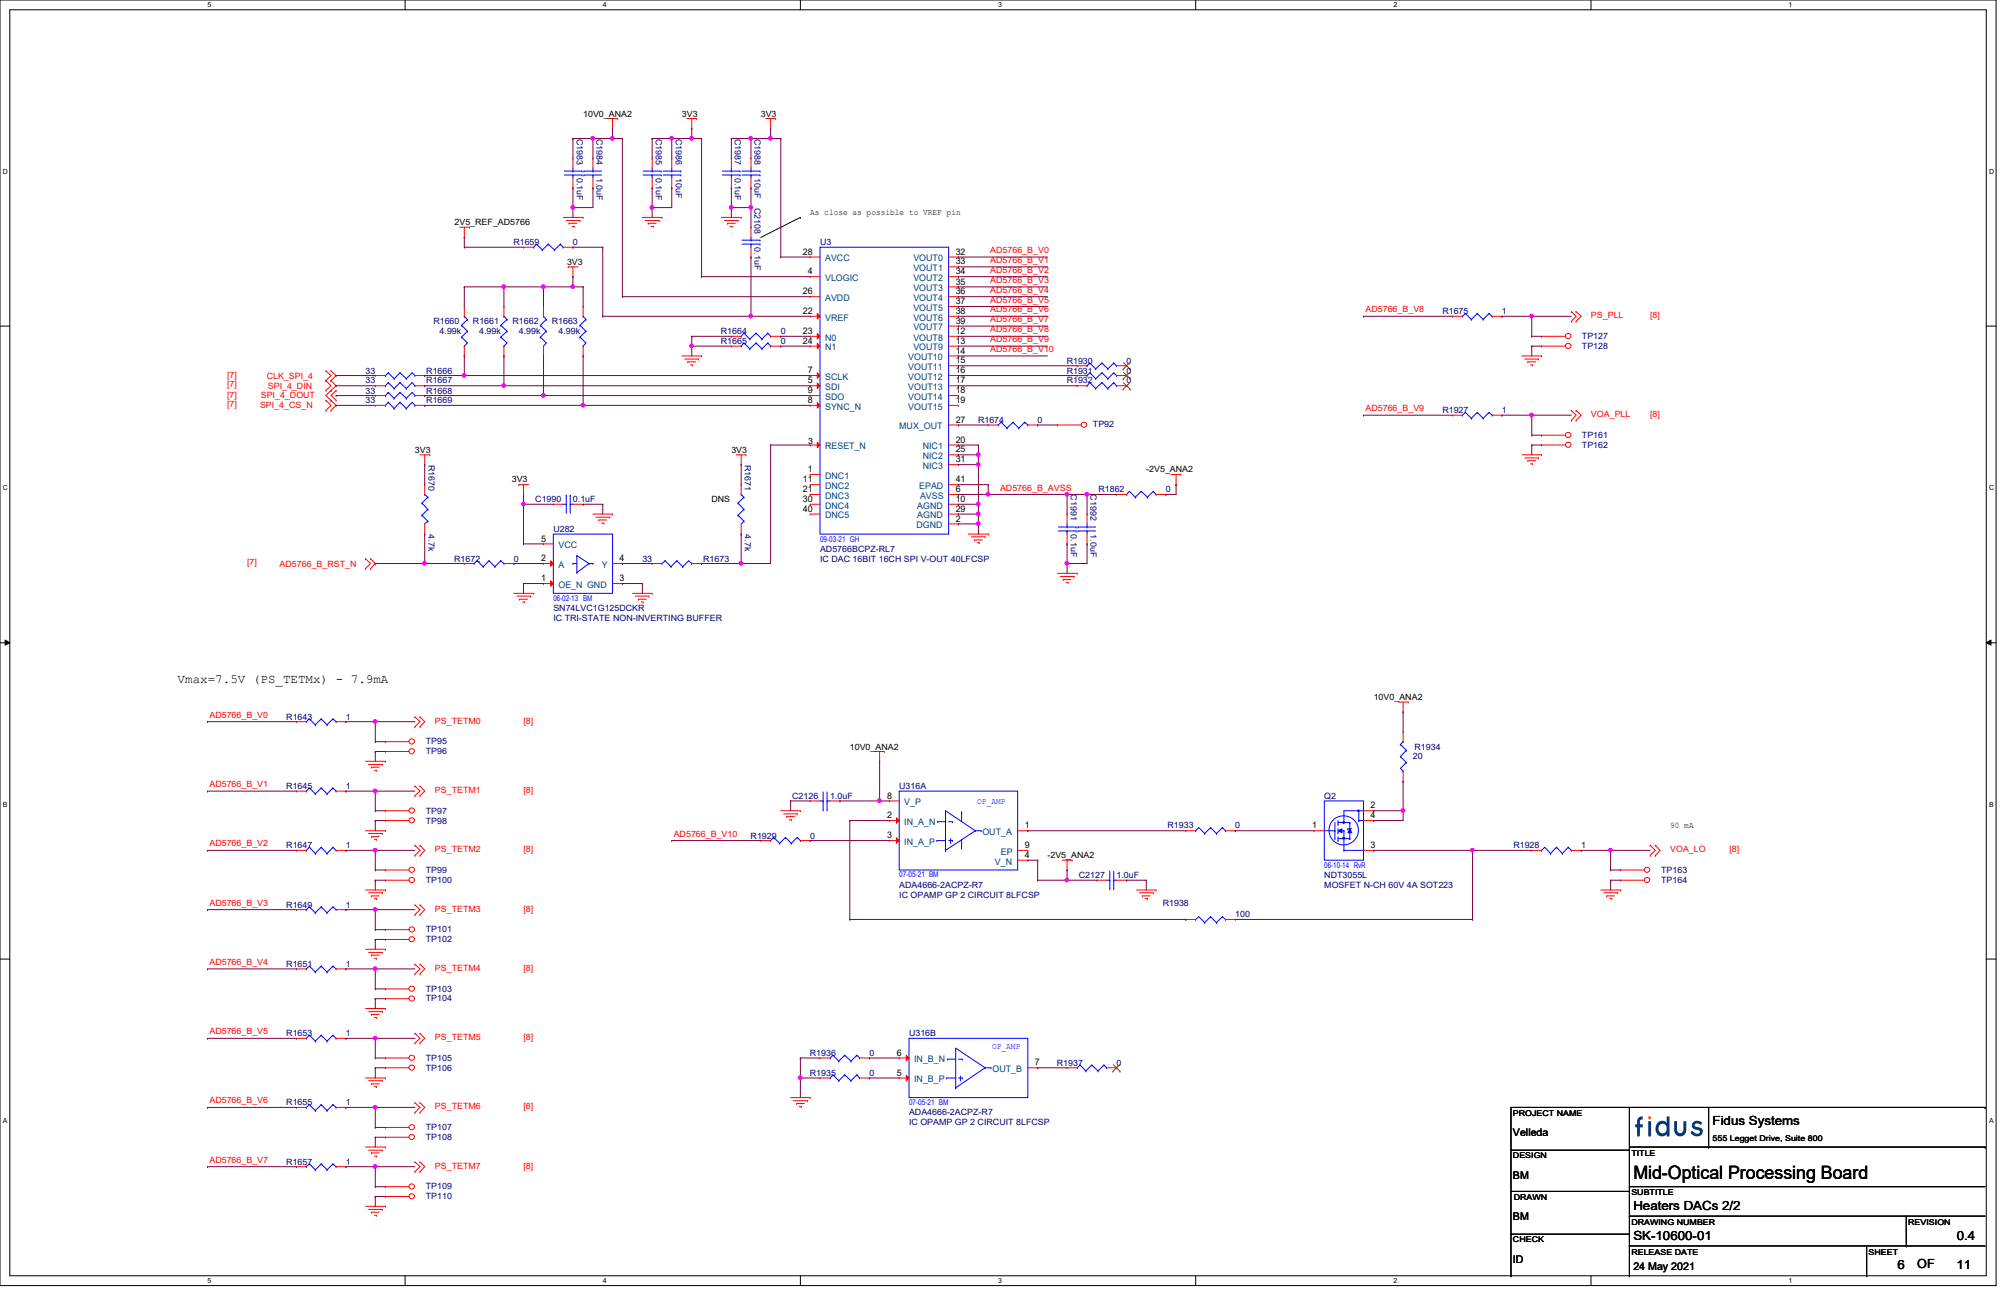
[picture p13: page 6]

As close as possible to VREF pin

SN74LVC1G125DCKR
IC TRI-STATE NON-INVERTING BUFFER

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

# INPUT POWER FROM FPGA BOARD

# Silk Screen: Main PWR

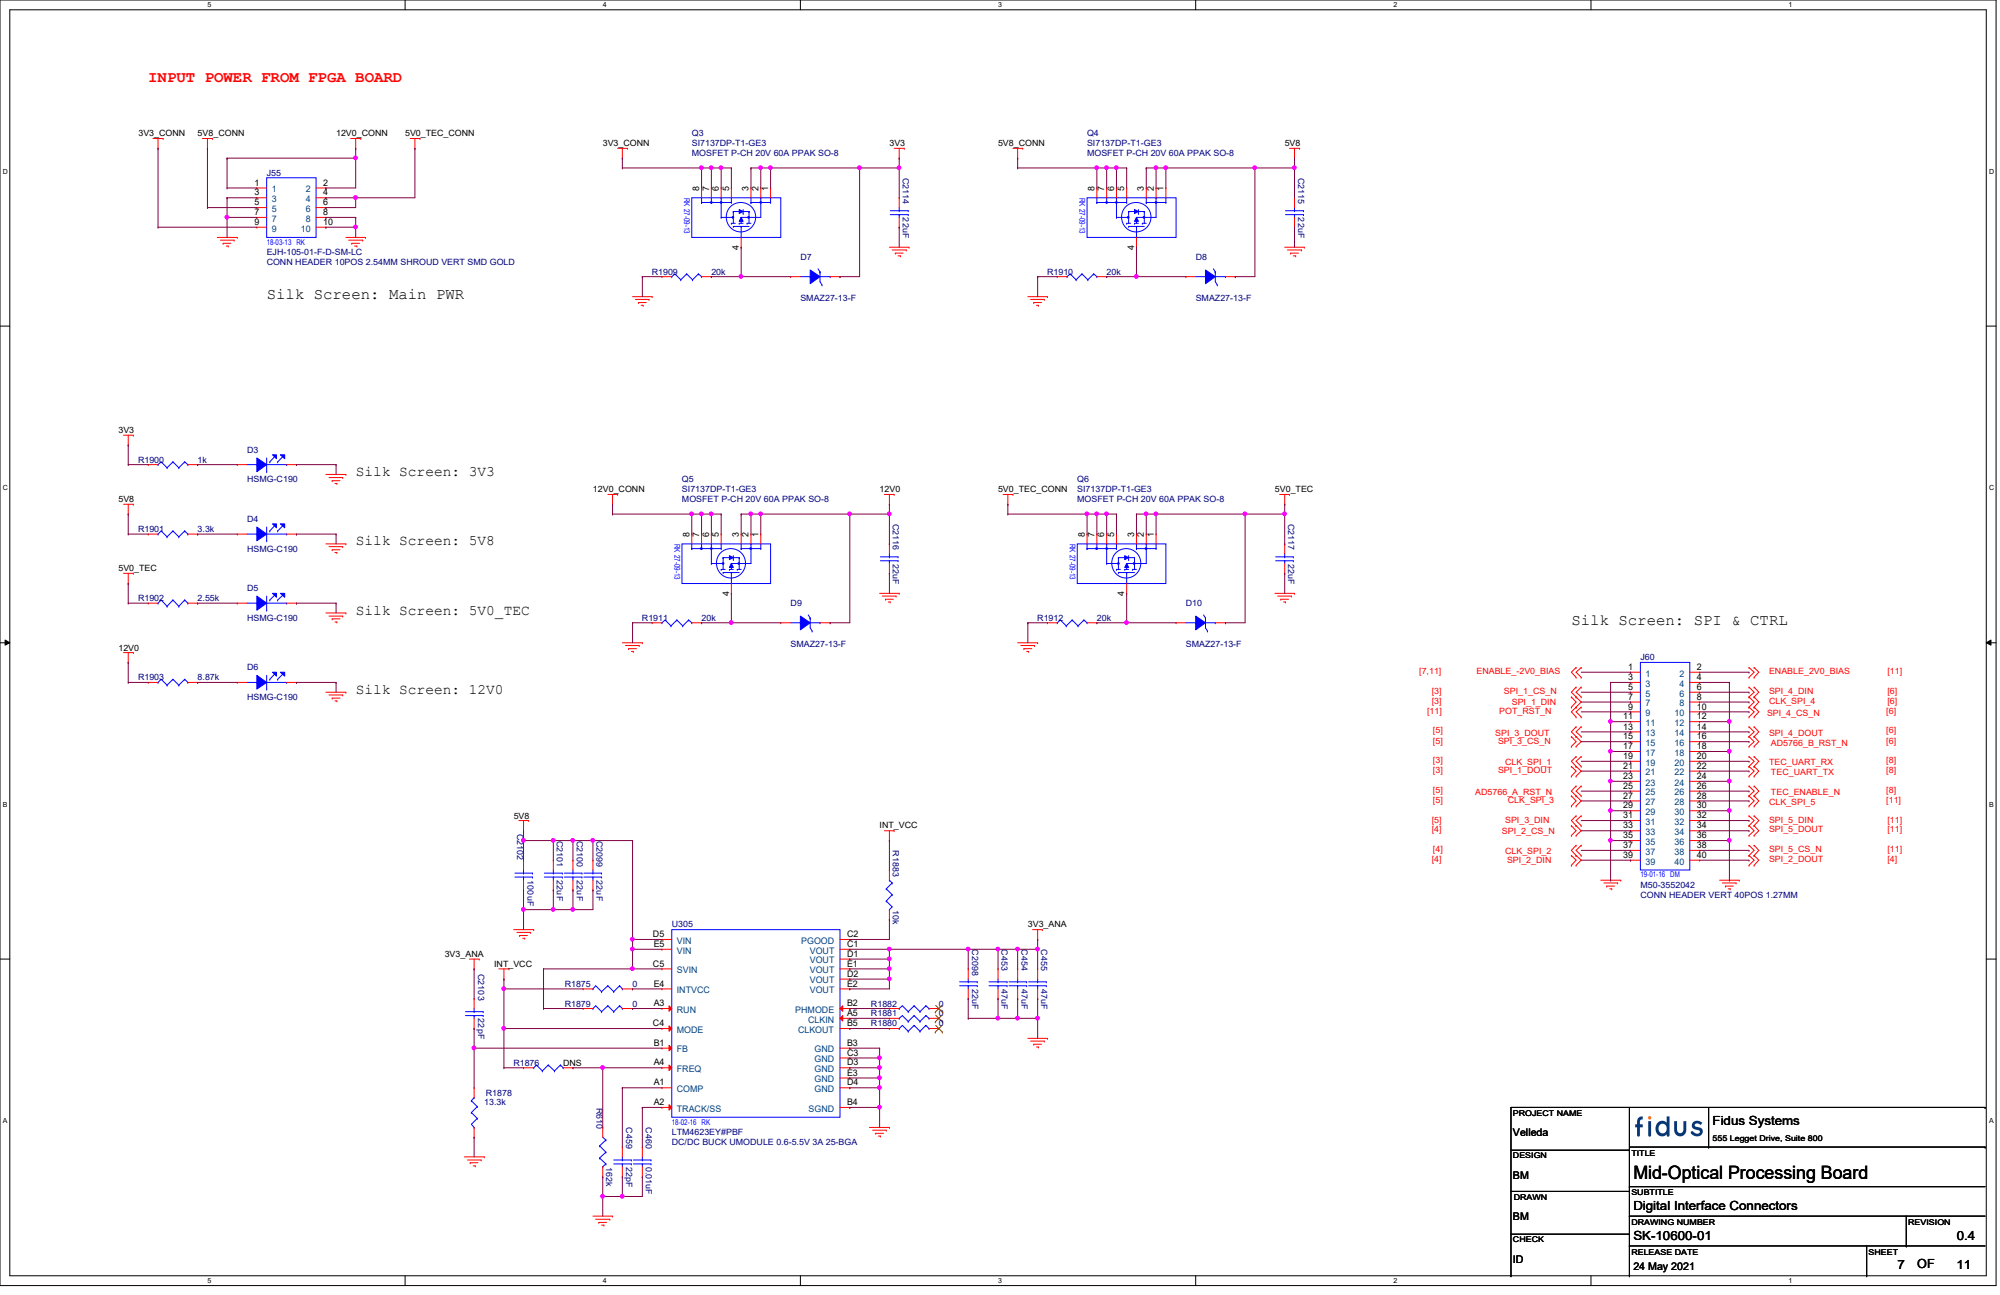
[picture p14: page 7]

EJH-105-01-F-D-SM-LC
CONN HEADER 10POS 2.54MM SHROUD VERT SMD GOLD

Silk Screen: SPI & CTRL

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

LTM4623EY#PBF
DC/DC BUCK UMODULE 0.6-5.5V 3A 25-BGA

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

# FROM OPTICAL HEAD BOARD
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

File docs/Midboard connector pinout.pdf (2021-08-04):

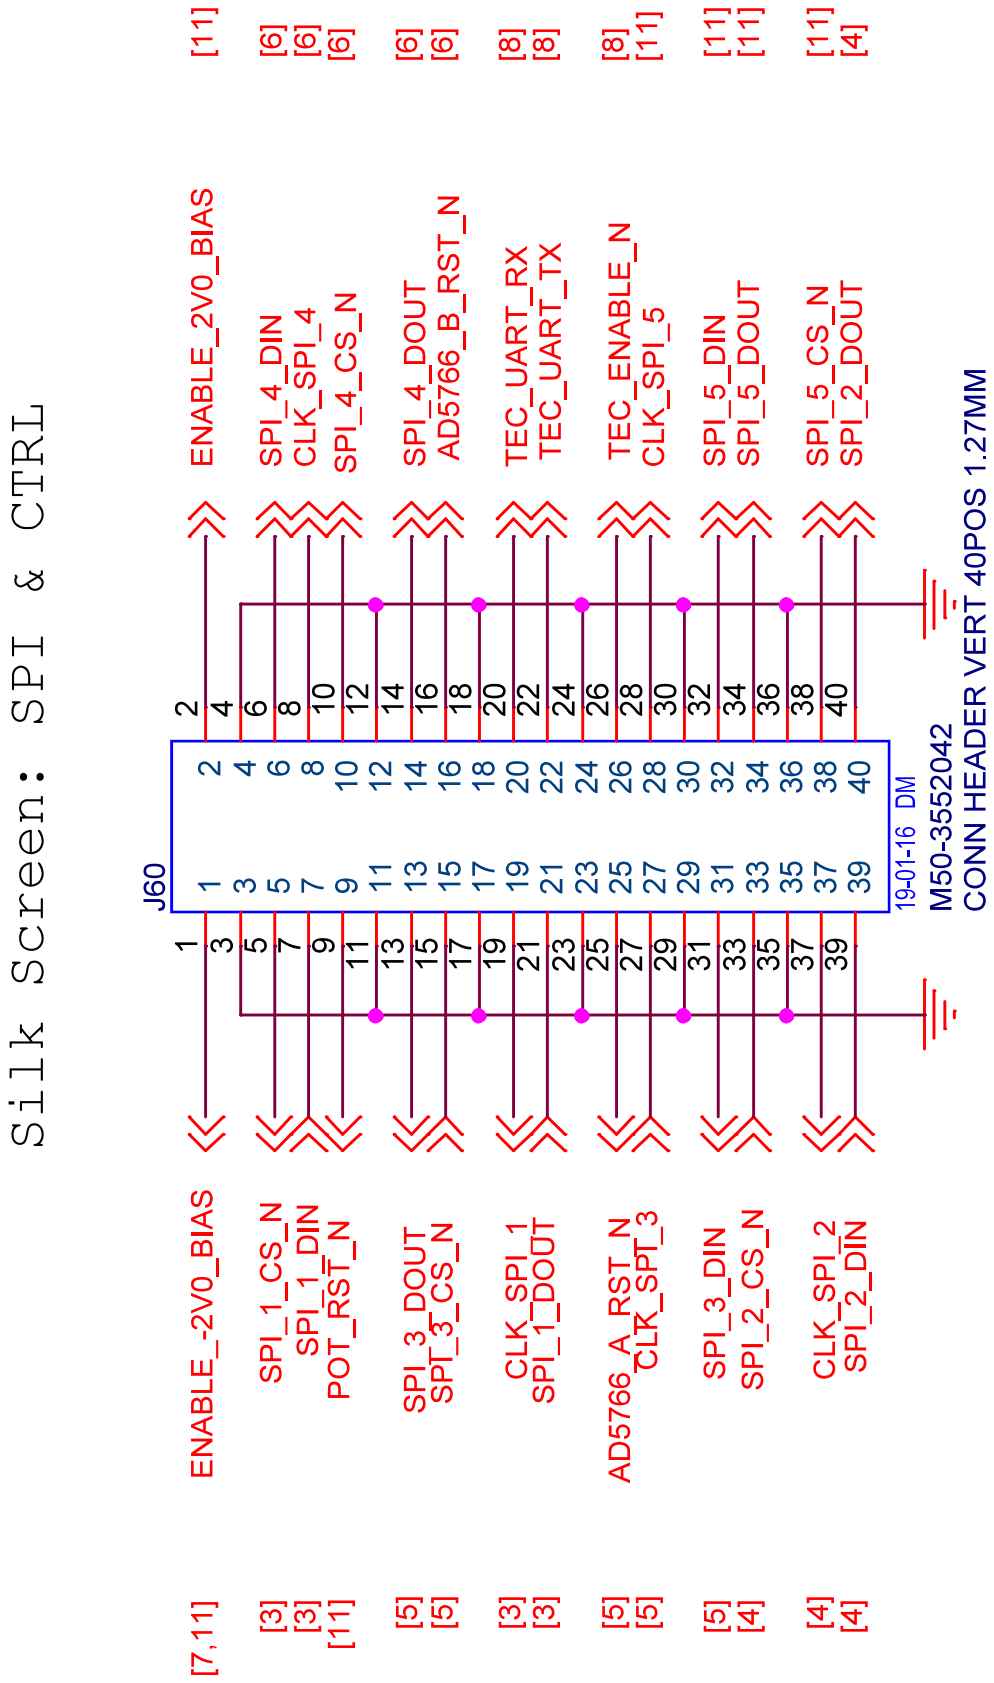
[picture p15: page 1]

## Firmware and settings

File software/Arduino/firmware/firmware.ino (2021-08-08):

/*
 * **** Firmware for Voyant Test Board (c)2021 josh.com
 * **** https://github.com/bigjosh/Voyant-test-board
 * 
 * To use this sketch, you must... 
 * 
 * 1. Install Arduino IDE https://www.arduino.cc/en/software
 * 2. Install Teensiduino from https://www.pjrc.com/teensy/td_download.html 
 * 3. Set the following in the Arduino Tools menu...
 * 
 *    Board     = Teensy->Teensyduino->Teensy 4.1
 *    USB Type  = Tripple Serial
 *    CPU Speed = 600Mhz (default)
 *    Port      = (find the Teensy 4.1 board on this list)
 */

#include <map>        // Used to store the list of SPI targets by index

// Start slow, we can always speed up later if needed. Global for now, but also possible to break this out per SPI target.
#define SPI_BPS 1000000    

// Max length in bytes of maximum SPI transaction. 
#define SPI_MAX_LEN 255

// Send comments over the command port that help in debugging problems
#define DEBUG true

#include "spi_target.h"
#include "uart_bridge.h"
#include "command_port.h"


// Define our SPI targets in a map so we can access them by `tag`

static const std::map< char , Spi_target > spi_targets = {

  // key in the map is the `target` char that the API uses to specify which SPI target
  // Taken directly from schamtics. The numbers here refer to the pin numbers on the Teensy. 
  // The tags are taken from the labels on the M50 connector diagram except for `A` which is on the AUX header.
  
  // spi_target( uint8_t mosi, uint8_t miso, uint8_t clk , uint8_t cs , uint32_t bps , uint8_t mode  ) 
  
  {'1', Spi_target( 33 , 32 , 31 , 30 , SPI_BPS , 2 ) },    // SPI1-AD7490, CLK idle HIGH, Sample on FALL, MSb first - https://www.analog.com/media/en/technical-documentation/data-sheets/AD7490.pdf
  {'2', Spi_target( 22 , 21 , 20 , 19 , SPI_BPS , 3 ) },    // SPI2-AD7124, CLK idle HIGH, Sample on RISE, MSb first - https://www.analog.com/media/en/technical-documentation/data-sheets/AD7124-4.pdf
  {'3', Spi_target( 26 ,  1 , 27 ,  0 , SPI_BPS , 2 ) },    // SPI3-AD5766, CLK idle HIGH, Sample on FALL, MSb first - https://www.analog.com/media/en/technical-documentation/data-sheets/ad5766-5767.pdf
  {'4', Spi_target( 11 , 12 , 13 , 10 , SPI_BPS , 2 ) },    // SPI4-AD5766, CLK idle HIGH, Sample on FALL, MSb first - https://www.analog.com/media/en/technical-documentation/data-sheets/ad5766-5767.pdf
  {'5', Spi_target( 17 , 16 , 15 , 14 , SPI_BPS , 2 ) },    // SPI5-AD5142, CLK idle HIGH, Sample on FALL, MSb first - https://www.analog.com/media/en/technical-documentation/data-sheets/AD5122_5142.pdf
  
  {'A', Spi_target(  4 ,  6 ,  2 , 37 , SPI_BPS , 0 ) },        // On the aux header on the right side of the PCB - For galvo. 
  
};


// Define our IO targets in a map so we can access them by `tag`

static const std::map< char , Io_target > io_targets = {

  // key in the map is the `target` char that the API uses to specify which IO target. 
  // The tags are arbitrary (but meant to hopefully be mnemonic)   
  // The pin refers to the Teensy pin number. 
  // io_target( uint8_t pin ) 

  // The comment is the label on the pin on the M50 connector
  
  {'N', Io_target( 24 ) },    // ENABLE_-2V0_BIAS
  {'P', Io_target( 25 ) },    // ENABLE_2V0_BIAS
  
  {'3', Io_target(  3 ) },    // AD5766_A_RST_N (SPI3)
  {'4', Io_target(  9 ) },    // AD5766_B_RST_N (SPI4)
  {'5', Io_target( 18 ) },    // POT_RST_N      (SPI5)

  {'T', Io_target(  5 ) },    // TEC_ENABLE_N   (TEC_UART)

  // The comment is the label on the Aux header  

  {'9', Io_target( 39 ) },    // D39
  {'8', Io_target( 38 ) },    // D38
  
};



// Define any desired UART bridges here
// uart_bridge(  HardwareSerial  * const real_port,  usb_serial2_class * const virtual_port  )

Uart_bridge uart_bridges[] = {

  Uart_bridge( &Serial2 , &SerialUSB1 ),      // TEC_UART connection on M50 to secondary USB serial connection to host
  
};

// Define our command port here

Command_port command_port( Serial , &spi_targets , &io_targets , DEBUG );          // The default serial connection to USB host.

void init_spi_targets() {

  // Hey C++, where is my `std::for_all`?
  for( auto &st : spi_targets) {
    st.second.init(); 
  }
  
}

void init_io_targets() {

  // Hey C++, where is my `std::for_all`?
  for( auto &io : io_targets) {
    io.second.init(); 
  }
  
}


// Call this periodically to keep the uart bridges fresh

void service_uart_bridges() {

  // Hey C++, where is my `std::for_all`?
  for( auto &ub : uart_bridges ) {
    ub.service(); 
  }
  
}

// Process any commands recieved on the command port

void service_command_port() {

  command_port.service(); 
  
}


void setup() {

  init_spi_targets();
  init_io_targets();

}



void loop() {

  // Maintain the uart bridges 
  service_uart_bridges();
  service_command_port();
  
}

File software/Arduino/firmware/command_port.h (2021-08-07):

struct Command_port {

  private :

    Stream &_s;
    const std::map< char , Spi_target > *_spi_targets; 
    const std::map< char , Io_target > *_io_targets; 
    const boolean _debug_flag;
    
    static const char COMMENT_CHAR = ';';

    static const char COMMAND_DELAY = 'D';
    static const char RESPONSE_DELAY = 'C';

    static const char COMMAND_TRANSFER = 'T';
    static const char RESPONSE_TRANSFER = 'S';
    
    static const char COMMAND_IO = 'I';
    static const char RESPONSE_IO = 'H';
    
    static const char RESPONSE_ERROR = 'E';

    static const unsigned LINE_MAX_LEN = (SPI_MAX_LEN*2) + 2; // The biggest command is SPI and has command byte+target byte+data in 2 byte ASCII.


    // Copied from https://stackoverflow.com/questions/6457551/hex-character-to-int-in-c
    // No error checking
    uint8_t hexdigit2value( const char c ) {
      uint8_t v = (c >= 'A') ? (c >= 'a') ? (c - 'a' + 10) : (c - 'A' + 10) : (c - '0');
      return v;
    }

    void send_response( const char c ) {
      _s.println( c );  
    }

    // Send the reponse code followed by the bytes in the buffer as ASCII hex digits
    void send_response_with_data( const char c , const uint8_t *b, unsigned len ) {
      _s.print( c );  

      while (len) {

        _s.printf( "%2.2x" , *b );      // Print as base 16 

        b++;
        len--;
      }

      _s.println();
      
    }

    void send_comment( const char *s ) {
        _s.print( COMMENT_CHAR );
        _s.println( s );        
    }
    
    void send_response_error( const char *s ) {

      if (_debug_flag) {
        send_comment( s );
      }
      send_response( RESPONSE_ERROR );  
    }

    void processIoCommand( const char *s , unsigned len ) {

      unsigned pos =0;    // Where we are at parsing the input line

      // First look up the tag

      if (len<=pos) {
        // Line too short for tag
        send_response_error("No tag, IO request too short");
        return;        
      }

      const char tag = s[pos++];    // First byte is the SPI target tag

      auto const io_target_tupple =  _io_targets->find( tag );

      if (io_target_tupple == _io_targets->end()) {
        // Tag not found in map
        send_response_error("Bad tag in IO request");
        return;
      }

      // Get the spi_target from the map tupple (I feel like {key,value} struct would be better than a tupple here, C++?)
      Io_target io_target = io_target_tupple->second;

      // Next parse the output level 

      if (len<=pos) {
        // Line too short for level
        send_response_error("No level, IO request too short");
        return;        
      }
      
      const char level_char = s[pos++];

      if (len!=pos) {        
        send_response_error("IO request too long");
        return;        
      }

      switch (level_char) {

        case '0': 
          io_target.set( false ); 
          break;
          
        case '1': 
          io_target.set( true ); 
          break;

        default:
          send_response_error("Invalid level in IO request");
          return;        
        
      }

    }    
    

    void processTransferCommand( const char *s , unsigned len ) {

      unsigned pos =0;    // Where we are at parsing the input line

      // First look up the tag

      if (len<=pos) {
        // Line too short for tag
        send_response_error("No tag, SPI request too short");
        return;        
      }

      const char tag = s[pos++];    // First byte is the SPI target tag

      auto const spi_target_tupple =  _spi_targets->find( tag );

      if (spi_target_tupple == _spi_targets->end()) {
        // Tag not found in map
        send_response_error("Bad tag in SPI request");
        return;
      }

      // Get the spi_target from the map tupple (I feel like {key,value} struct would be better than a tupple here, C++?)
      Spi_target spi_target = spi_target_tupple->second;

      // Next parse the ASCII hex digits to a byte[]


      // A more responsible programmer would only allocate the actual number of bytes here, but this parser is already starting to feel bloated and we have plenty of RAM
      byte mosi_data_buffer[SPI_MAX_LEN];

      unsigned data_buffer_len = 0;

      while (pos<len) {

        if (data_buffer_len >=SPI_MAX_LEN) {
          send_response_error("More than SPI_MAX_LEN bytes in SPI request");
          return;
        }

        // Parse each pair of hex digits

        const char hdigit = s[pos++];

        if (pos>=len) {
          send_response_error("Incomplete ASCII hex byte in SPI request");
          return;        
        }

        if (!isxdigit(  hdigit )) {
          send_response_error("Invalid high ASCII hex digit in SPI request");
          return;        
        }

        const char ldigit = s[pos++];

        if (!isxdigit(  ldigit )) {
          send_response_error("Invalid low ASCII hex digit in SPI request");
          return;        
        }

        const uint8_t b = hexdigit2value( hdigit ) << 4 | hexdigit2value( ldigit ) ;

        mosi_data_buffer[ data_buffer_len++ ] = b;
                        
      }

      byte miso_data_buffer[data_buffer_len];   // Buffer for incoming SPI bytes
      

      spi_target.transferBuffer( mosi_data_buffer , miso_data_buffer , data_buffer_len );


      send_response_with_data( RESPONSE_TRANSFER , miso_data_buffer , data_buffer_len );
              
    }

    
    // Note that delay will overflow if greater than ULONG_MAX
    void processDelayCommand( const char *arg , const unsigned len ) {
      
      unsigned long delay_ms =0;

      unsigned pos =0;    

      if (pos==len) {
          send_response_error("Delay request missing millis");
          return;        
      }
      
      // Parse number of millis
      while (pos<len) {
        const char digit = arg[pos];
        if (!isdigit(digit)) {
          send_response_error("Bad digit in delay");
          return;
        }
        delay_ms*=10;
        delay_ms += digit-'0';

        pos++;
      }

      delay(delay_ms);

      send_response( RESPONSE_DELAY );
    }

    char inputLine[LINE_MAX_LEN]; // Leave room for terminating null
    unsigned inputLineLen=0;
    
    void processLine( char *l , unsigned len ) {

      switch (l[0]) {
        
        case COMMAND_DELAY:
            
            processDelayCommand( l+1 , len-1 );
            break;

        case COMMAND_TRANSFER:
        
            processTransferCommand( l+1 , len-1 );
            break;

        case COMMAND_IO:
        
            processIoCommand( l+1 , len-1 );
            break;
            

        case COMMENT_CHAR:

            // This page intionally left blank
            break;

        default:
            send_response_error( "Unknown command");
            break;
            
      }              
    }
    

  public:
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

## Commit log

2021-06-26 Create parts
    [TEENSY_4.1.stp, m50-3552042_asm.stp]
2021-06-26 Teensy pin names customized
2021-06-27 Clean up some traces. Add copper ground pour.
2021-06-27 Add mounting holes.
2021-06-29 Updated 3d mode for 20-pin headers
    [m20-7822042_asm.stp]
2021-08-04 Create Midboard connector pinout.pdf
2021-08-05 Soft SPI and Serial Bridge written and working.
2021-08-06 Feature complete. Still need to actually type in pin lists.
    [X] IO pins
    [ ] actually type in all the targets
    [ ] clean up API docs
2021-08-06 SPI targets typed in
    [-] actually type in all the targets
    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
2021-08-06 IO pin targets typed in
    [X] actually type in all the targets
    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
2021-08-07 New SPI modes
    Does not seem to work with the AD7124 that I have attached, but could be dead board or something else?
2021-08-07 Messing with SPI code to get the AD7124 to read.
2021-08-07 Update SPI code
2021-08-08 Make AD5766 scope trace look nicer
2021-08-23 Add signal trace for D39 example
